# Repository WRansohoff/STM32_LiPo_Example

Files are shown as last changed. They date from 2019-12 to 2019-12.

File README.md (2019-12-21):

# LiPo Battery-Powered STM32 Board

This is a small board which incorporates an `MCP73831` Lithium battery charger. It has a maximum charge rate of 500mA, but it is simple and easy to use. A JST PH-2 connector is used for the battery; it seems like small lithium batteries have more or less standardized on this type of connector, but double-check the polarity before you plug anything in.

A micro-USB plug is used as a 5V supply to charge the battery, and a small slide switch is used to turn the board's power on or off. Two 100KΩ resistors also form a voltage divider for the microcontroller to read the battery voltage through pin A0's ADC channel, and I'm planning to add an example firmware which reads and prints the battery voltage over UART in the near future.

This board will not work with the almost-identical `MCP73832` chip - the difference is that the 'status' pin has a tri-state output on the `MCP73831` and an open-drain output on the `MCP73832`. So with the former, you can have separate 'charging in progress' and 'done charging' LEDS. But with the latter, you can only have one 'done charging' LED directly connected to the pin. I dunno, maybe that saves you $.005 per unit when you order 10 million at a time or something.

# Board Renders

As seen through OSHPark's purple-colored glasses:

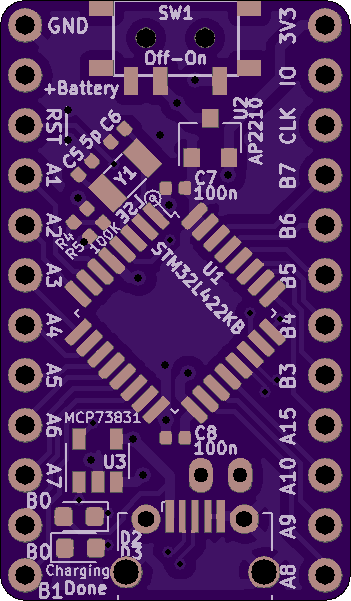
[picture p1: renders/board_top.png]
Top

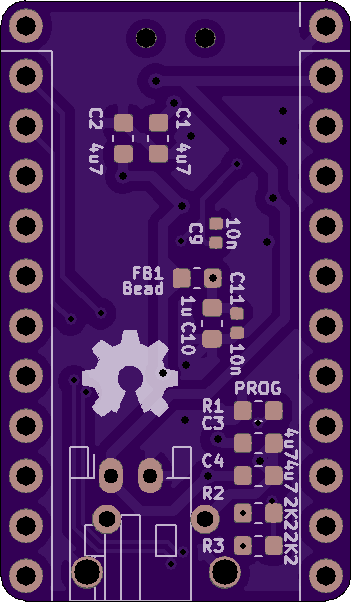
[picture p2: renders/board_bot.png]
Bottom


# Safety

**Before assembling this board or trying to incorporate elements into your design, spend some time ressearching lithium battery safety precautions. Always independently verify lithium battery circuits before assembling them. Never leave lithium batteries unattended when they are charging or in use.**

Here's a link to the datasheet for the battery-charging chip. Double-check your designs against its recommendations:

http://ww1.microchip.com/downloads/en/DeviceDoc/20001984g.pdf

I'm not even going to try to make a comprehensive list of safety precautions to take when handling lithium batteries, and working with circuitry that interacts with them is even more dangerous. Do your own research on how to work with them safely, start out with small batteries in the 100s of milliAmp-hours, and most importantly, don't blame me if anything goes wrong. The MIT license is very permissive, but it also says there's no warranty :)

# Future Work

* I should use a voltage regulator with a 'power good' pin and connect it to the reset line, to reduce problems with power supply glitches when the battery gets low.

* I haven't tested the USB data lines, and if they do work, there isn't much space to add the optional-but-recommended TVS diodes such as an `SP0503BAHT`. It might be better to use a cheaper microcontroller and only use the USB port for power.

* There's no "heartbeat" LED, and it's nice to have at least one user-controlled LED on a board for all kinds of reasons. For one thing, there's no way for the board to indicate that it has a low battery.

* I need to polish a simple test firmware which reads the battery voltage and prints it out over UART every few seconds.

* It's usually silly to use a linear voltage regulator in a simple battery-powered application, because you waste a bunch of power. Using a buck converter would be a better choice here.

* Per [#1](https://github.com/WRansohoff/STM32_LiPo_Example/issues/1), I should connect the `MCP73831` ground pin to a larger ground plane to help it dissipate heat and maybe reach its maximum charge current of 500mA.

* It might be a good idea to move the 'Ground' and '+Battery' breadboard pins farther apart, to make accidental shorts less likely.

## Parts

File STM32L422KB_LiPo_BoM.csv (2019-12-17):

Part ID | Part type | Part size (Imperial) | Part value | Example Digikey Item | Cost (qty: x) | Comment
C1, C2, C3, C4 | Capacitor | 0603 | 4.7 μF | https://www.digikey.com/short/p2hdqt | $0.68 | Decoupling capacitors for the battery charger and voltage regulator. Use X5R or X7R ceramic capacitors rated for at least 6.3V
C5, C6 | Capacitor | 0402 | 5 pF | https://www.digikey.com/short/pdhnbc | $0.20 | Decoupling capacitors for the low-speed external oscillator crystal. Actual values will depend on your crystal; 5pF is a rough estimate. Use C0G / NP0 capacitors.
C7, C8 | Capacitor | 0402 | 100 nF | https://www.digikey.com/short/p2hrz2 | $0.20 | Decoupling capacitors for the microcontroller / etc. Prefer X5 or X7 ceramic capacitors.
C10 | Capacitor | 0603 | 1 μF | https://www.digikey.com/short/pdhnbv | $0.10 | Decoupling capacitor for the analog voltage supply. Use X7 ceramic capacitors.
C9, C11 | Capacitor | 0402 | 10 nF | https://www.digikey.com/short/p2hr54 | $0.20 | Decoupling capacitors for the reset button and analog voltage supply. Use X7 ceramic capacitors.
FB1 | Ferrite Bead | 0603 | N/A | https://www.digikey.com/short/p2h080 | $0.10 | Ferrite bead for filtering noise out of the analog voltage supply.
R1 | Resistor | 0603 | >= 2 KΩ, 1% | https://www.digikey.com/short/pdh2b4 | $0.10 | This resistor sets the rate of charge for the battery charger. Charge current = 1000 / R, so use 2KΩ for a 500mA charge rate, 10KΩ for a 100mA charge rate, etc. 500mA is the maximum charge rate. Use resistors with 1% precision to ensure you get the right charge rate.
R2, R3 | Resistor | 0603 | 220Ω - 4.7KΩ | https://www.digikey.com/short/p2hdw9 | $0.20 | Current-limiting resistors for the "charging" and "done charging" LEDs. Use higher values to make the LEDs dimmer.
R4, R5 | Resistor | 0402 | 100 KΩ, 1% | https://www.digikey.com/short/pdh2b7 | $0.20 | Resistors for the voltage divider which lets the microcontroller read its own battery voltage. Use resistors with 1% precision, or choose two which have almost identical values.
D2 | LED | 0603 | Red | https://www.digikey.com/short/pdh21f | $0.14 | "Charging" LED, lit up when the battery is charging.
D3 | LED | 0603 | Green | https://www.digikey.com/short/pdh21m | $0.14 | "Done" LED, lit up when the battery has finished charging.
Y1 | Crystal | 3.2x1.5 mm | 32.768 KHz | https://www.digikey.com/short/p2h0zh | $0.41 | "Low-Speed External" oscillator crystal.
J1 | USB Connector | Micro-B Socket | N/A | https://www.digikey.com/short/pdhw81 | $2.07 | Micro-USB connector for battery charging and USB communication. I'm still working through a reel of cheap-o micro-B sockets that I ordered awhile ago, but they seem to fit the "Wuerth_629105150521" footprint in KiCAD.
J2, J3 | Pin Header | 0.1" | 1x12 | https://www.digikey.com/short/p1rnnz | $0.60 | Pin headers for the board edges to plug into a breadboard. It's cheaper to bulk-order bunches of 1x40-row breakaway headers, but you can also order them in specific sizes.
J5 | Battery Connector | JST PH-2 | 1x2 | https://www.digikey.com/short/p1r08b | $0.17 | JST PH-2 connector for the lithium battery connector. This seems to be a common semi-standard among small "pouch cells" and even some prepackaged cylindrical cells.
SW1 | Slide Switch | SMD | SPDT | https://www.digikey.com/short/pd2qtz | $0.91 | Power on/off switch.
U1 | Microcontroller | QFP-32 (7x7 mm) | STM32L422KB | https://www.digikey.com/short/p1rdc0 | $4.60 | I chose the STM32L422KB because it has a USB peripheral and can operate off of as little as 1.8V. But if you don't care about working USB, an STM32L0 chip would be cheaper. And if you don't care about low-voltage operation, an STM32F0x2 chip would be cheaper.
U2 | Voltage Regulator | SOT-23 | AP2210 | https://www.digikey.com/short/p1rnv3 | $0.42 | Simple 3-pin 300mA 3.3V low-dropout linear regulator. They say that good things come in threes...
U3 | Battery Charger | SOT-25 | MCP73831 | https://www.digikey.com/short/pdhw7v | $0.56 | Battery charging circuit. I use the 4.2V version with "3.7V nominal / 4.2V charge" lithium batteries.
Total |  |  |  |  | $12.00

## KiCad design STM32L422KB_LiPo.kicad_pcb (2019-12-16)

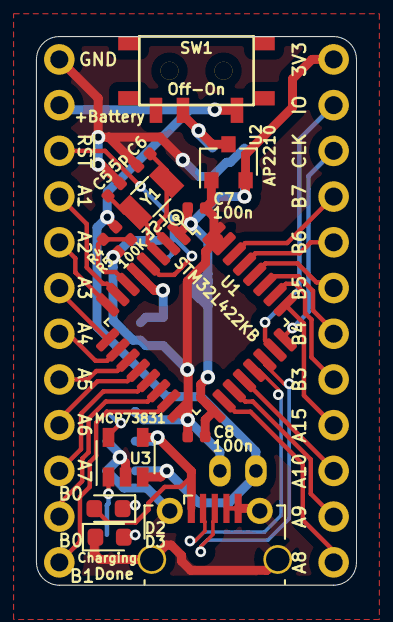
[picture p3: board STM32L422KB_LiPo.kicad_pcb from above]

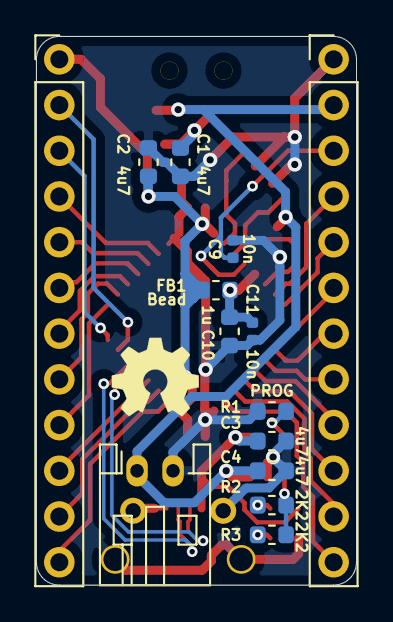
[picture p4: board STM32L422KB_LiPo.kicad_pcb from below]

Board: 2 copper layers, 17.8 x 30.5 mm, 28 parts (14 on the bottom side), 36 nets.

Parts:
C1, C2, C3, C4: 4u7; C_0603_1608Metric
C5, C6: 5p; C_0402_1005Metric
C7, C8: 100n; C_0402_1005Metric
C9, C11: 10n; C_0402_1005Metric
C10: 1u; C_0603_1608Metric
D2: Charging; LED_0603_1608Metric
D3: Done; LED_0603_1608Metric
FB1: Bead; R_0603_1608Metric
J1: uUSB; MyMicroUSB
J2: GPIO1; PinHeader_1x12_P2.54mm_Vertical
J3: GPIO2; PinHeader_1x12_P2.54mm_Vertical
J5: Battery; JST_PH_S2B-PH-K_1x02_P2.00mm_Horizontal
R1: PROG; R_0603_1608Metric
R2, R3: 2K2; R_0603_1608Metric
R4, R5: 100K; R_0402_1005Metric
SW1: Off-On; mini_slide_switch
U1: STM32L422KB; LQFP-32_7x7mm_P0.8mm
U2: AP2210; SOT-23
U3: MCP73831; SOT-23-5
Y1: LSE; Crystal_SMD_3215-2Pin_3.2x1.5mm

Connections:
+5V: C3.1, D2.2, J1.1, U3.4
+BATT: C4.1, J2.2, J5.1, R4.1, SW1.1, U3.3
A0: R4.2, R5.1, U1.6
A1: J2.4, U1.7
A2: J2.5, U1.8
A3: J2.6, U1.9
A4: J2.7, U1.10
A5: J2.8, U1.11
A6: J2.9, U1.12
A7: J2.10, U1.13
A8: J3.12, U1.18
A9: J3.11, U1.19
A10: J3.10, U1.20
A15: J3.9, U1.25
B0: J2.11, U1.14
B1: J2.12, U1.15
B3: J3.8, U1.26
B4: J3.7, U1.27
B5: J3.6, U1.28
B6: J3.5, U1.29
B7: J3.4, U1.30
GND: C1.1, C2.2, C3.2, C4.2, C5.2, C6.1, C7.2, C8.2, C9.2, C10.1, C11.2, D3.1, J1.4, J1.5, J1.6, J2.1, J5.2, R1.2, R5.2, U1.16, U1.31, U1.32, U2.1, U3.2
unnamed: C1.2, SW1.2, U2.3
unnamed: C5.1, U1.3, Y1.1
unnamed: C6.2, U1.2, Y1.2
unnamed: C10.2, C11.1, FB1.2, U1.5
unnamed: D2.1, R2.1
unnamed: D3.2, R3.1
unnamed: R1.1, U3.5
unnamed: R2.2, R3.2, U3.1
SWCLK: J3.3, U1.24
SWDIO: J3.2, U1.23
USB_D+: J1.3, U1.22
USB_D-: J1.2, U1.21
VDD: C2.1, C7.1, C8.1, FB1.1, J3.1, U1.1, U1.17, U2.2
~RST: C9.1, J2.3, U1.4

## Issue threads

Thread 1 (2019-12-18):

MCP73831/2 thermal throttling

deltabeard, 2019-12-18:
Hi again.

I've actually been using the MCP73832 since a week ago on a breadboard using a SOT-23 to DIP converter board. Despite programming it to charge at 500mAh, it was charging at around 320mAh instead due to thermal throttling.

This is because this IC has a thermal resistance of 230 C/W, so it gets hot very quickly. This is reduced to <130 C/W with a ground plane. It may be worth attaching your MCP73831 directly to a large ground plane, instead of through a via to stop it from thermal throttling.

I attached a tiny wire as a heatsink to my MCP73832, so it only thermal throttles to 420mAh now...

WRansohoff, 2019-12-21:
Oh, interesting - thank you for the tip!

I usually try to include large contiguous ground planes, but this board ended up being a little bit space-constrained with the USB port, toggle switch, and battery connector. 2-layer boards designed to fit a breadboard can get a little cramped, but maybe I could move the charging IC to the other side of the board which is less crowded.

Anyways, thanks again for the information. I should do more testing to characterize these projects' real-world performance, but I already feel sort of behind on writing firmwares and learning how the USB and SD/MMC protocols work. Busy, busy, busy :smile:.

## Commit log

2019-12-16 Add initial KiCAD project files.
    [STM32L422KB_LiPo.kicad_pcb, STM32L422KB_LiPo.sch]
2019-12-16 Add project-specific schematic library and footprint files.
2019-12-16 Add a basic bill of materials for the board.
    [STM32L422KB_LiPo_BoM.csv]
2019-12-16 Add initial board renders
2019-12-16 Move board renders to the same line.
2019-12-16 Add BoM entries for the LEDs and crystal oscillator.
    [STM32L422KB_LiPo_BoM.csv]
2019-12-17 Add battery connector to the bill of materials.
    [STM32L422KB_LiPo_BoM.csv]
2019-12-21 Add a to-do item to improve the battery charger's ability to dissipate heat into the board.
2019-12-21 Add to-do item to move ground/battery breadboard pins farther apart.
